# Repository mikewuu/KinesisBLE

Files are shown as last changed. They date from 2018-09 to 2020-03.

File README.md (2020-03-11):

# Wireless Kinesis Advantage BLE (Bluetooth Low Energy)

Turns the [Kinesis Advantage Keyboard](https://www.kinesis-ergo.com/shop/advantage2/) keyboard into a wireless BLE keyboard with a few extra features. Built with Adafruit's nRF52 Feather Arduino boards.

For instructions, see the **[wiki](https://github.com/sysdevmike/KinesisBLE/wiki)**. For more details on the build check out the **[project](https://hackaday.io/project/161578-wireless-ble-kinesis-advantage-custom-controller)**.

## Many thanks to

- [Yin Zhong](https://summivox.wordpress.com/2016/06/03/keyboard-matrix-scanning-and-debouncing/) - Explains a better way to handle debouncing.
- [Stapelberg](https://michael.stapelberg.ch/posts/2018-04-17-kinx-keyboard-controller/) - Double mention as I ported his debouncing used in his KinX controller to Matt's firmware.
- [Matt Vilim](https://github.com/mattvilim/FeatherCtrl) - New firmware is a fork of his FeatherCtrl project.
- [Adafruit](https://www.adafruit.com/product/3406) - Great documentation, libs and support.
- [afriggeri](https://github.com/afriggeri/kb) - The original firmware borrowed heavily from his [Blanck Keyboard](https://medium.com/@friggeri/the-blanck-keyboard-24afe12e81a) project.
- [Stapelberg](https://michael.stapelberg.de/posts/2013-03-21-kinesis_custom_controller/) - Michael Stapelberg's custom controller inspired this project. His PCB routing was inspirational.
- [Humble Hacker](http://humblehacker.com/blog/20100720/hacking-the-kinesis-contoured-keyboard/) - Detailed write-up helped me understand the keyboard matrix.
- [PCBgogo](http://www.pcbgogo.com) - All the boards were made by these guys. Fast turn-around.

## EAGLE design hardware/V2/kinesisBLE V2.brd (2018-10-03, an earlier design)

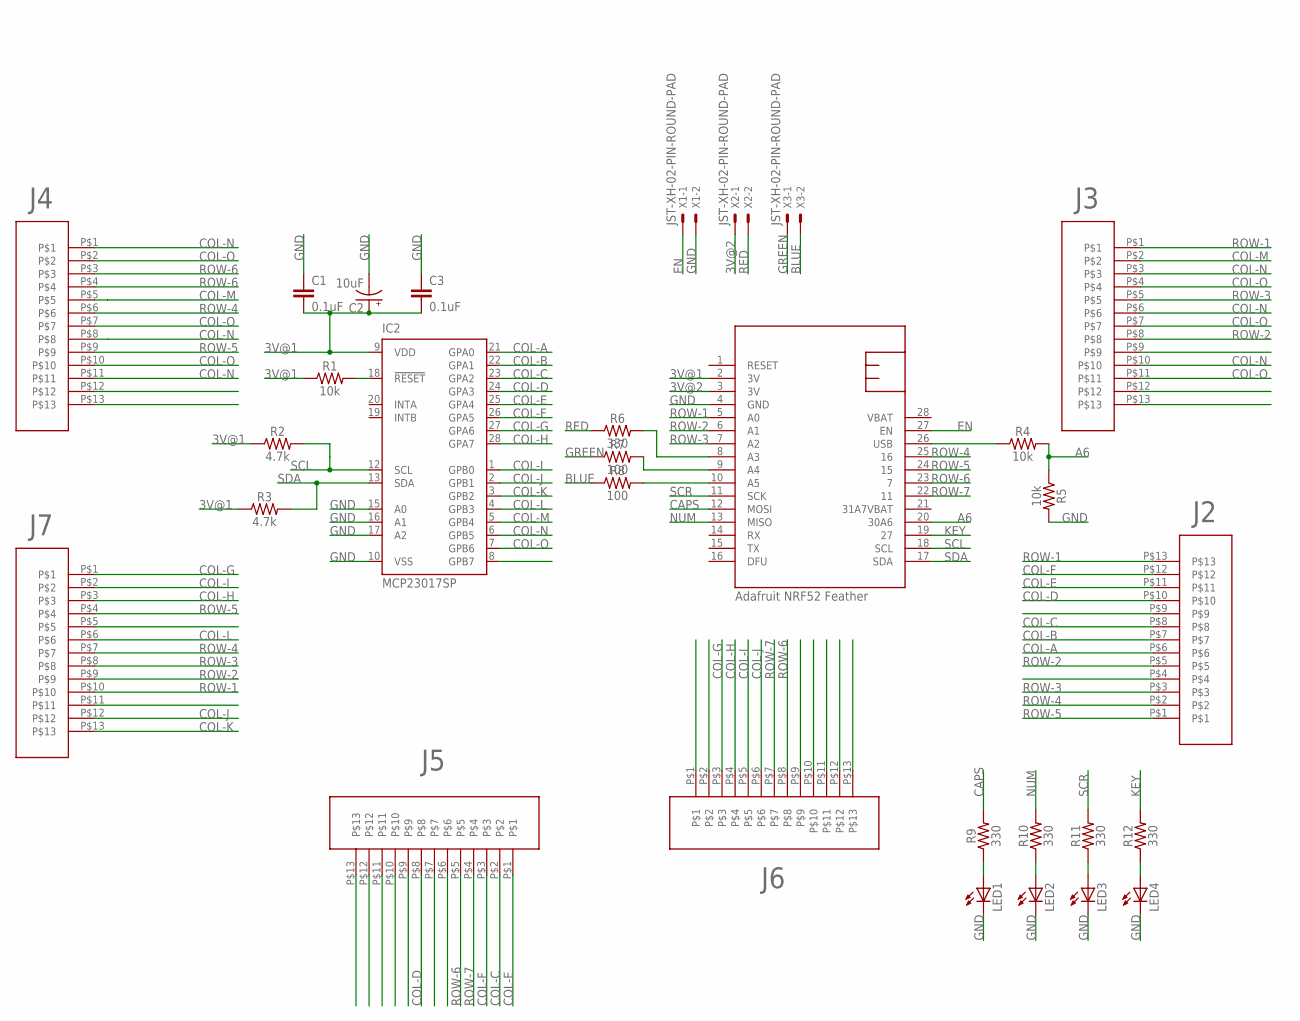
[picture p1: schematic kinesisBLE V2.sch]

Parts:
C1, C3: 0.1uF; CAP-PTH-SMALL-KIT
C2: 10uF; CPOL-RADIAL-2.5MM-5MM
IC2: MCP23017SP; DIL28-3
LED1, LED2, LED3, LED4: LED3MM
R1, R4, R5: 10k; AXIAL-0.3
R2, R3: 4.7k; AXIAL-0.3
R6, R9, R10, R11, R12: 330; AXIAL-0.3
R7, R8: 100; AXIAL-0.3
U$1: NRF52FEATHER
U$2, U$3, U$4, U$5, U$6, U$7: TOPLINKS_STAPELBERG
X1, X2, X3: JST-XH-02-PIN-ROUND-PAD; JST-XH-02-PACKAGE-ROUND-PAD

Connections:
3V@1: C1.2, C2.1 (+), C3.2, IC2.9 (VDD), R1.P$1 (1), R2.P$1 (1), R3.P$1 (1), U$1.2 (3V)
3V@2: U$1.3 (3V), X2.1
A6: R4.P$2 (2), R5.P$1 (1), U$1.20 (30A6)
BLUE: R8.P$1 (1), X3.2
CAPS: R9.P$2 (2), U$1.12 (MOSI)
COL-A: IC2.21 (GPA0), U$5.P$6
COL-B: IC2.22 (GPA1), U$5.P$7
COL-C: IC2.23 (GPA2), U$5.P$8, U$6.P$2
COL-D: IC2.24 (GPA3), U$5.P$10, U$6.P$8
COL-E: IC2.25 (GPA4), U$5.P$11, U$6.P$1
COL-F: IC2.26 (GPA5), U$5.P$12, U$6.P$3
COL-G: IC2.27 (GPA6), U$4.P$1, U$7.P$3
COL-H: IC2.28 (GPA7), U$4.P$3, U$7.P$4
COL-I: IC2.1 (GPB0), U$4.P$2, U$7.P$5
COL-J: IC2.2 (GPB1), U$4.P$12, U$7.P$6
COL-K: IC2.3 (GPB2), U$4.P$13
COL-L: IC2.4 (GPB3), U$4.P$6
COL-M: IC2.5 (GPB4), U$2.P$5, U$3.P$2
COL-N: IC2.6 (GPB5), U$2.P$1, U$2.P$8, U$2.P$11, U$3.P$3, U$3.P$6, U$3.P$10
COL-O: IC2.7 (GPB6), U$2.P$2, U$2.P$7, U$2.P$10, U$3.P$4, U$3.P$7, U$3.P$11
EN: U$1.27 (EN), X1.1
GND: C1.1, C2.2 (-), C3.1, IC2.10 (VSS), IC2.15 (A0), IC2.16 (A1), IC2.17 (A2), LED1.K (C), LED2.K (C), LED3.K (C), LED4.K (C), R5.P$2 (2), U$1.4 (GND), X1.2
GREEN: R7.P$1 (1), X3.1
KEY: R12.P$2 (2), U$1.19 (27)
unnamed: LED1.A, R9.P$1 (1)
unnamed: IC2.18 (!RESET), R1.P$2 (2)
unnamed: R4.P$1 (1), U$1.26 (USB)
unnamed: R6.P$2 (2), U$1.8 (A3)
unnamed: R7.P$2 (2), U$1.9 (A4)
unnamed: R8.P$2 (2), U$1.10 (A5)
unnamed: LED2.A, R10.P$1 (1)
unnamed: LED3.A, R11.P$1 (1)
unnamed: LED4.A, R12.P$1 (1)
NUM: R10.P$2 (2), U$1.13 (MISO)
RED: R6.P$1 (1), X2.2
ROW-1: U$1.5 (A0), U$3.P$1, U$4.P$10, U$5.P$13
ROW-2: U$1.6 (A1), U$3.P$8, U$4.P$9, U$5.P$5
ROW-3: U$1.7 (A2), U$3.P$5, U$4.P$8, U$5.P$3
ROW-4: U$1.25 (16), U$2.P$6, U$4.P$7, U$5.P$2
ROW-5: U$1.24 (15), U$2.P$9, U$4.P$4, U$5.P$1
ROW-6: U$1.23 (7), U$2.P$3, U$2.P$4, U$6.P$5, U$7.P$8
ROW-7: U$1.22 (11), U$6.P$4, U$7.P$7
SCL: IC2.12 (SCL), R2.P$2 (2), U$1.18 (SCL)
SCR: R11.P$2 (2), U$1.11 (SCK)
SDA: IC2.13 (SDA), R3.P$2 (2), U$1.17 (SDA)
VBAT: U$1.28 (VBAT)

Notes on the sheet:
Adafruit NRF52 Feather

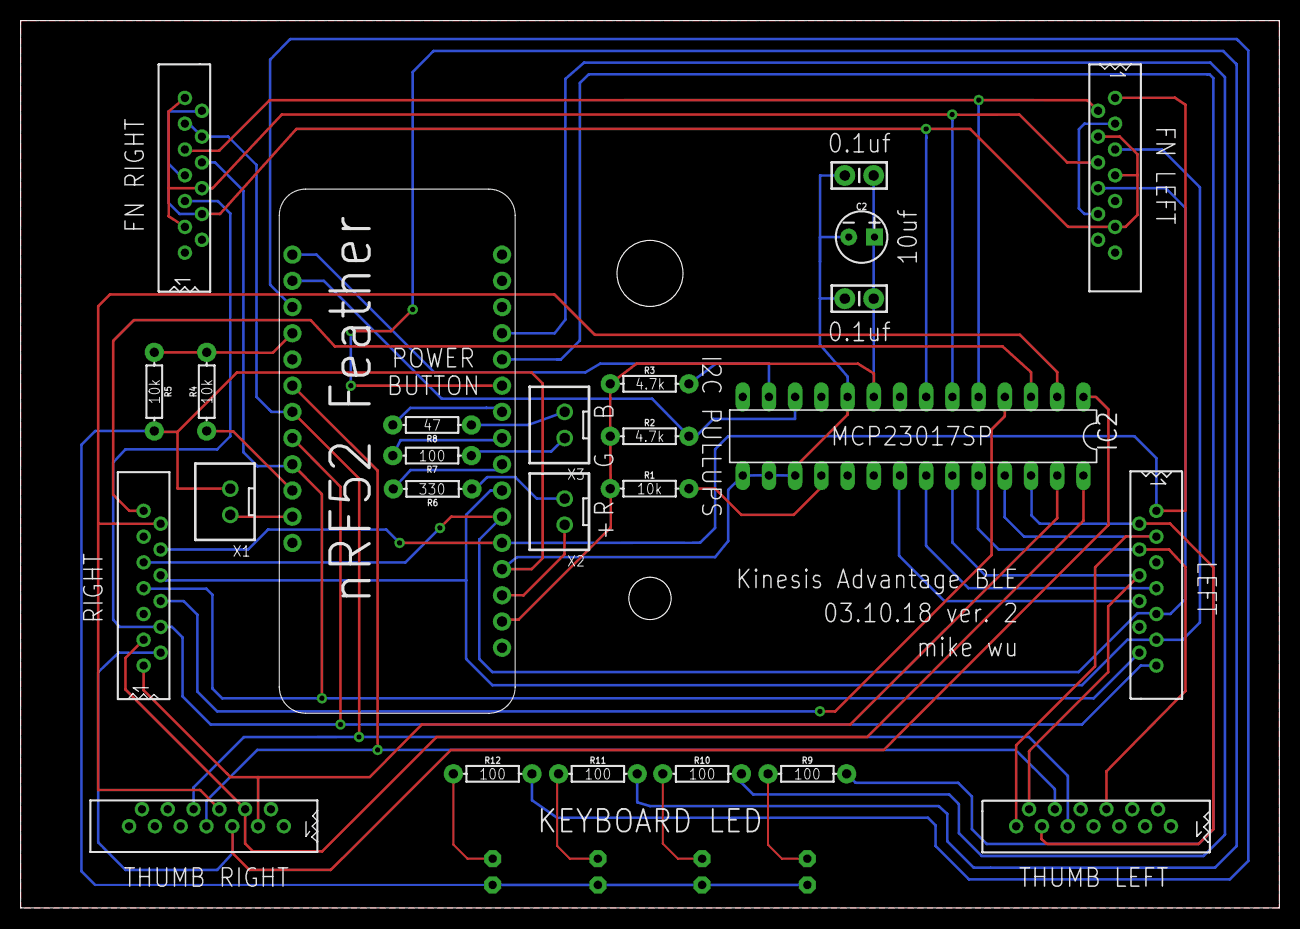
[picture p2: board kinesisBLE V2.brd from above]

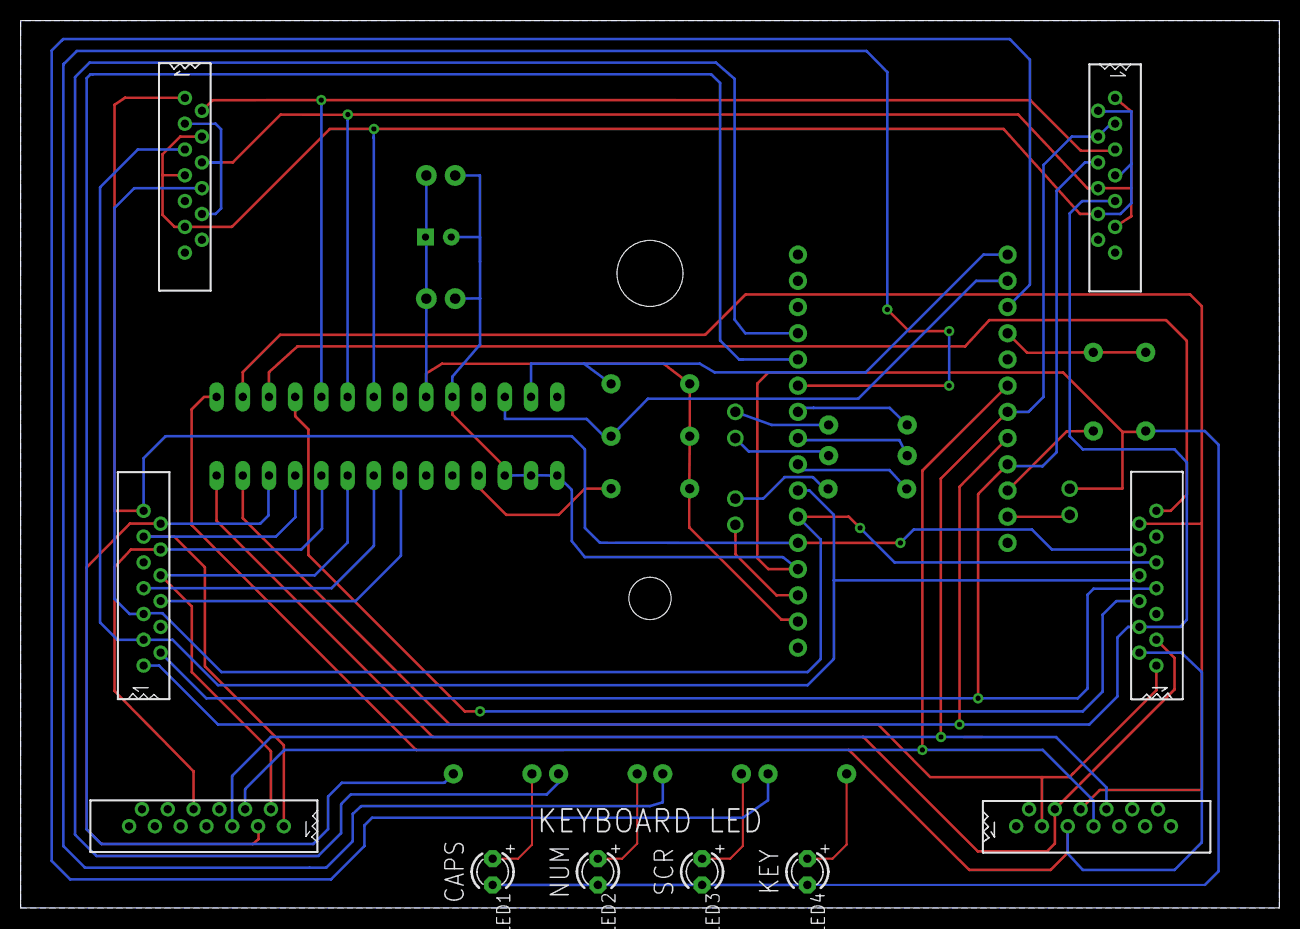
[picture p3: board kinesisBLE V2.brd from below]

Board: 2 copper layers, 122.0 x 86.0 mm, 30 parts (7 on the bottom side), 45 nets.

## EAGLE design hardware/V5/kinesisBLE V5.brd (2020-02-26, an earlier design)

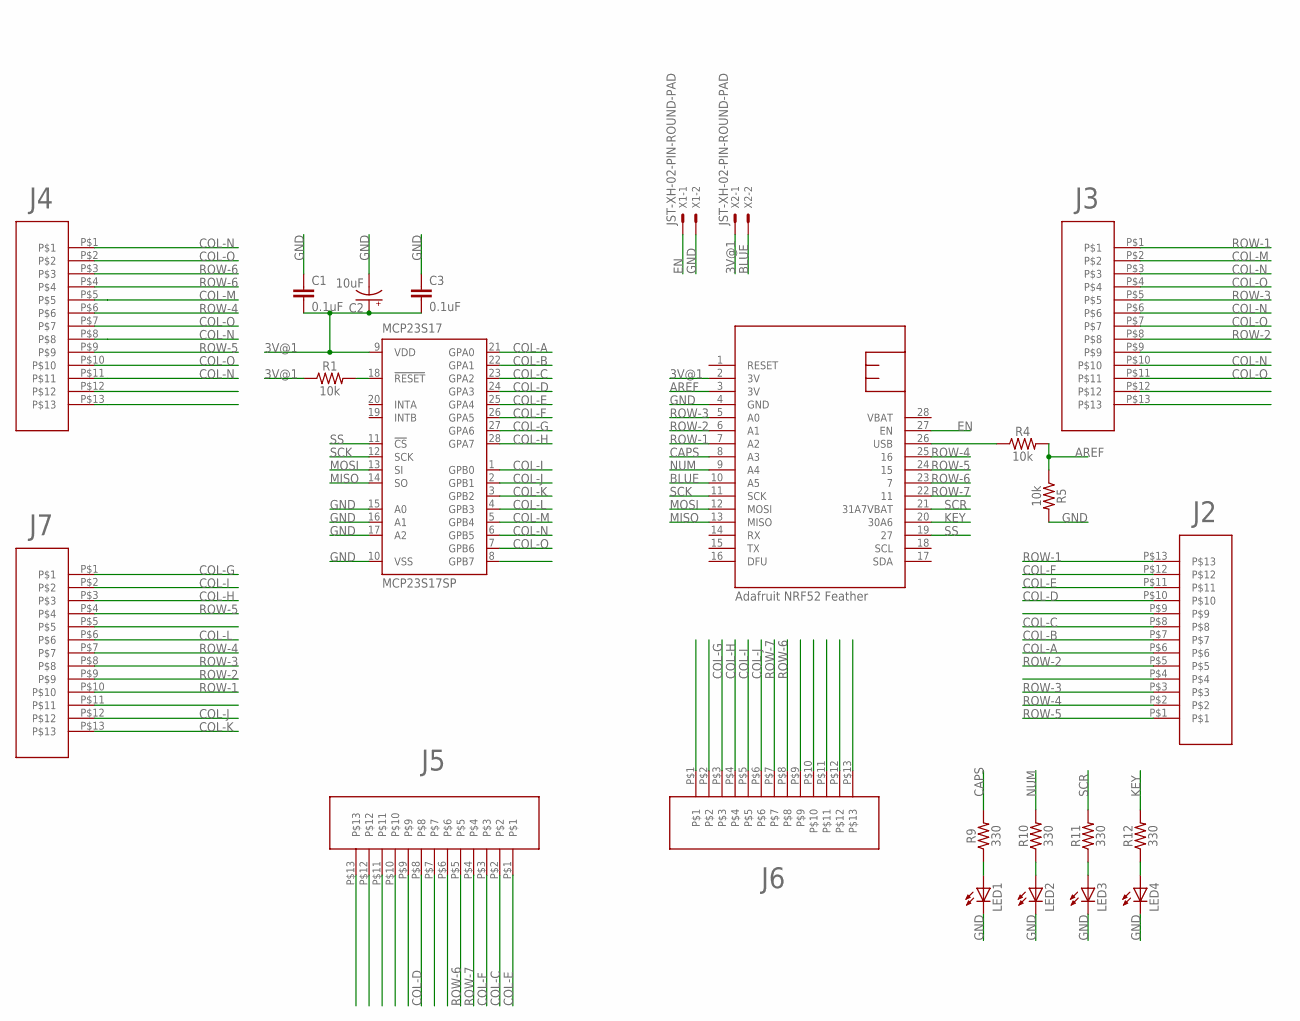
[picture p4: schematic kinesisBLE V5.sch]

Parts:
C1, C3: 0.1uF; CAP-PTH-SMALL-KIT
C2: 10uF; CPOL-RADIAL-2.5MM-5MM
LED1, LED2, LED3, LED4: LED3MM
MCP23S17: MCP23S17SP; DIL28-3
R1, R4, R5: 10k; AXIAL-0.3
R9, R10, R11, R12: 330; AXIAL-0.3
U$1: NRF52FEATHER
U$2, U$3, U$4, U$5, U$6, U$7: TOPLINKS_STAPELBERG
X1, X2: JST-XH-02-PIN-ROUND-PAD; JST-XH-02-PACKAGE-ROUND-PAD

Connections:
3V@1: C1.2, C2.1 (+), C3.2, MCP23S17.9 (VDD), R1.P$1 (1), U$1.2 (3V), X2.1
AREF: R4.P$2 (2), R5.P$1 (1), U$1.3 (3V)
BLUE: U$1.10 (A5), X2.2
CAPS: R9.P$2 (2), U$1.8 (A3)
COL-A: MCP23S17.21 (GPA0), U$5.P$6
COL-B: MCP23S17.22 (GPA1), U$5.P$7
COL-C: MCP23S17.23 (GPA2), U$5.P$8, U$6.P$2
COL-D: MCP23S17.24 (GPA3), U$5.P$10, U$6.P$8
COL-E: MCP23S17.25 (GPA4), U$5.P$11, U$6.P$1
COL-F: MCP23S17.26 (GPA5), U$5.P$12, U$6.P$3
COL-G: MCP23S17.27 (GPA6), U$4.P$1, U$7.P$3
COL-H: MCP23S17.28 (GPA7), U$4.P$3, U$7.P$4
COL-I: MCP23S17.1 (GPB0), U$4.P$2, U$7.P$5
COL-J: MCP23S17.2 (GPB1), U$4.P$12, U$7.P$6
COL-K: MCP23S17.3 (GPB2), U$4.P$13
COL-L: MCP23S17.4 (GPB3), U$4.P$6
COL-M: MCP23S17.5 (GPB4), U$2.P$5, U$3.P$2
COL-N: MCP23S17.6 (GPB5), U$2.P$1, U$2.P$8, U$2.P$11, U$3.P$3, U$3.P$6, U$3.P$10
COL-O: MCP23S17.7 (GPB6), U$2.P$2, U$2.P$7, U$2.P$10, U$3.P$4, U$3.P$7, U$3.P$11
EN: U$1.27 (EN), X1.1
GND: C1.1, C2.2 (-), C3.1, LED1.K (C), LED2.K (C), LED3.K (C), LED4.K (C), MCP23S17.10 (VSS), MCP23S17.15 (A0), MCP23S17.16 (A1), MCP23S17.17 (A2), R5.P$2 (2), U$1.4 (GND), X1.2
KEY: R12.P$2 (2), U$1.20 (30A6)
MISO: MCP23S17.14 (SO), U$1.13 (MISO)
MOSI: MCP23S17.13 (SI), U$1.12 (MOSI)
unnamed: LED1.A, R9.P$1 (1)
unnamed: MCP23S17.18 (!RESET), R1.P$2 (2)
unnamed: R4.P$1 (1), U$1.26 (USB)
unnamed: LED2.A, R10.P$1 (1)
unnamed: LED3.A, R11.P$1 (1)
unnamed: LED4.A, R12.P$1 (1)
NUM: R10.P$2 (2), U$1.9 (A4)
ROW-1: U$1.7 (A2), U$3.P$1, U$4.P$10, U$5.P$13
ROW-2: U$1.6 (A1), U$3.P$8, U$4.P$9, U$5.P$5
ROW-3: U$1.5 (A0), U$3.P$5, U$4.P$8, U$5.P$3
ROW-4: U$1.25 (16), U$2.P$6, U$4.P$7, U$5.P$2
ROW-5: U$1.24 (15), U$2.P$9, U$4.P$4, U$5.P$1
ROW-6: U$1.23 (7), U$2.P$3, U$2.P$4, U$6.P$5, U$7.P$8
ROW-7: U$1.22 (11), U$6.P$4, U$7.P$7
SCK: MCP23S17.12 (SCK), U$1.11 (SCK)
SCR: R11.P$2 (2), U$1.21 (31A7VBAT)
SS: MCP23S17.11 (!CS), U$1.19 (27)
VBAT: U$1.28 (VBAT)

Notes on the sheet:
Adafruit NRF52 Feather

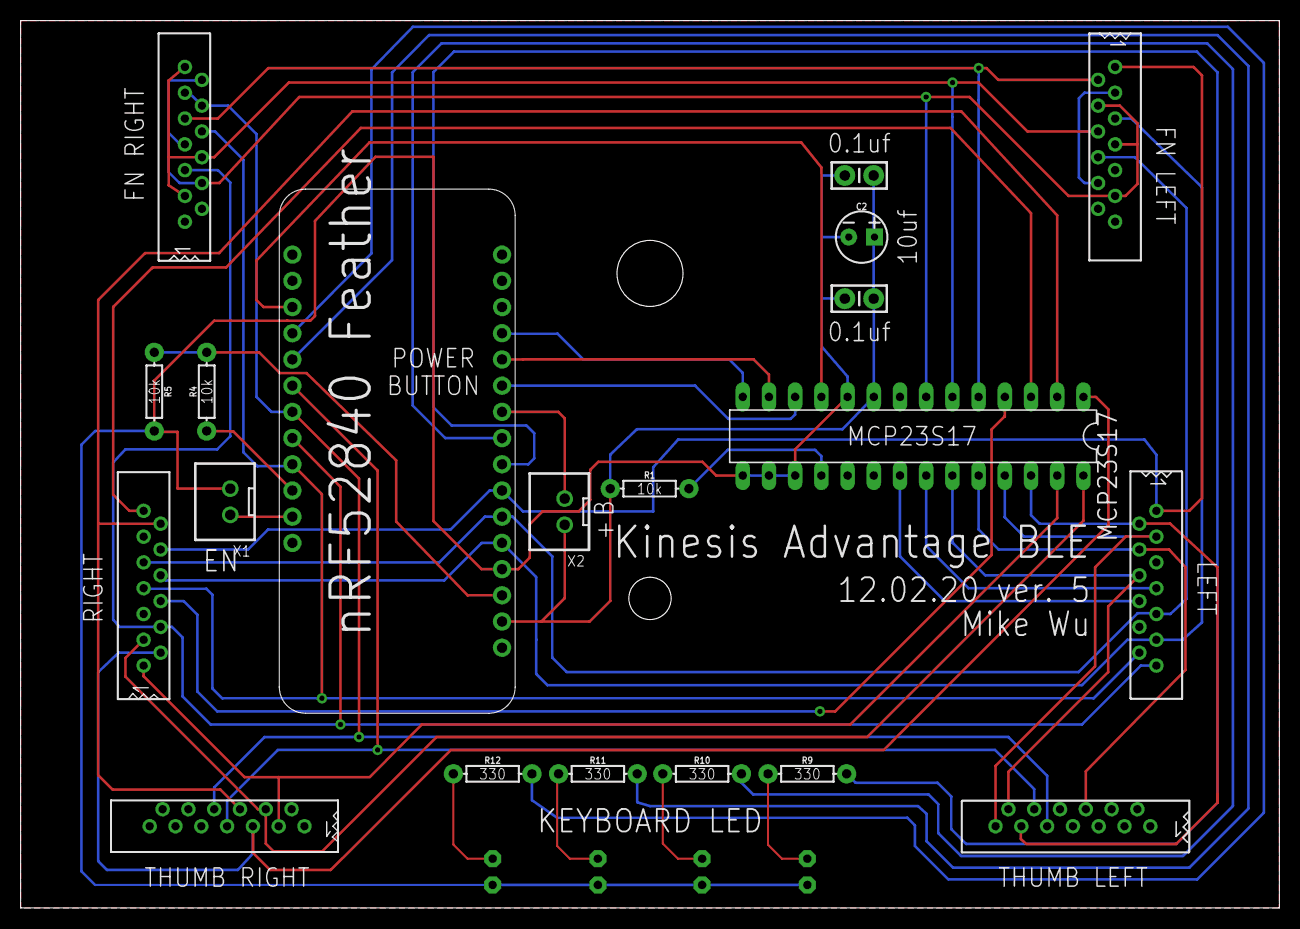
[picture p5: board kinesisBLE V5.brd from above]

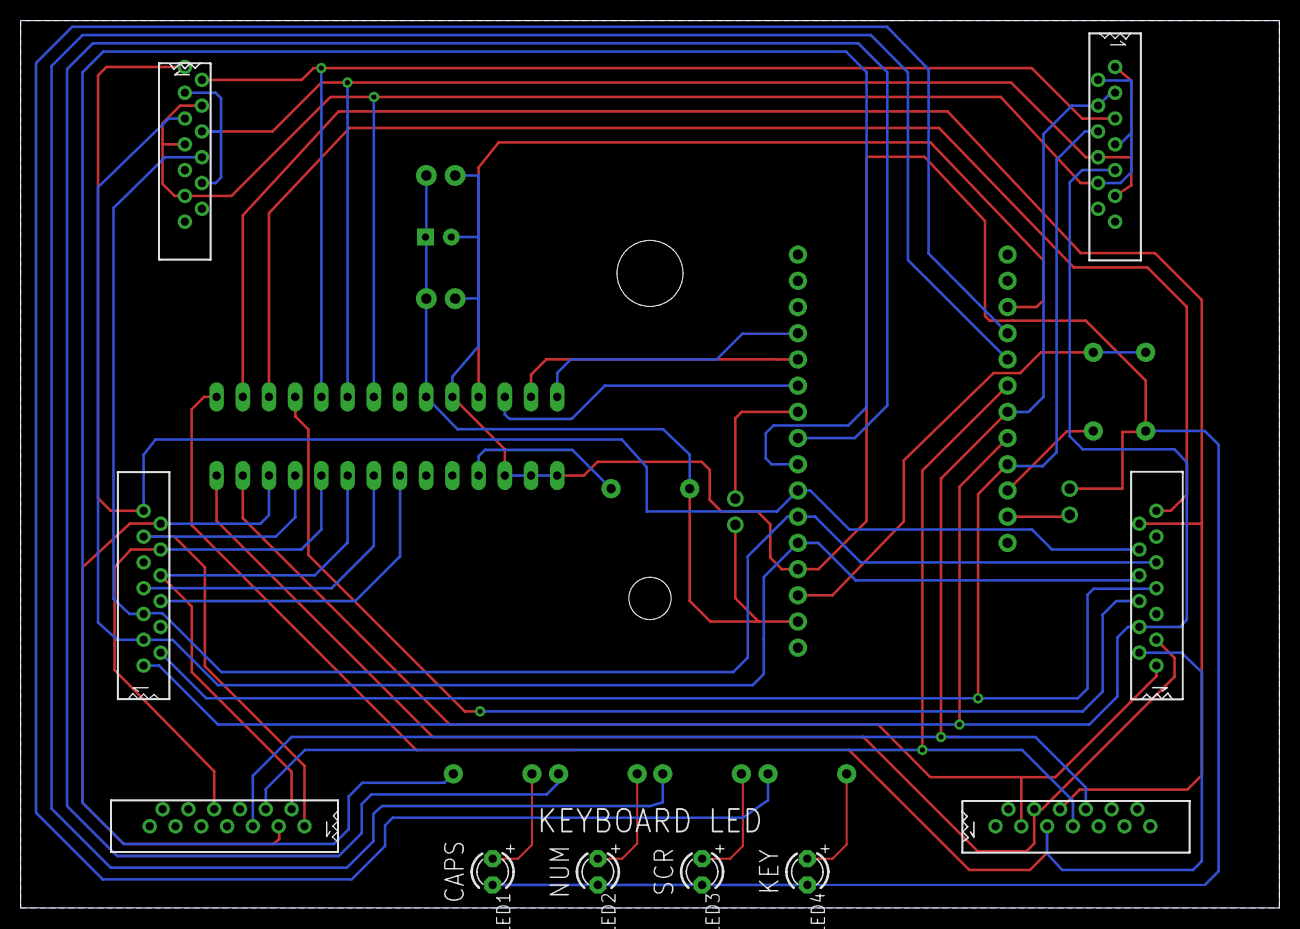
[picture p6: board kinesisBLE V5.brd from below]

Board: 2 copper layers, 122.0 x 86.0 mm, 24 parts (7 on the bottom side), 41 nets.

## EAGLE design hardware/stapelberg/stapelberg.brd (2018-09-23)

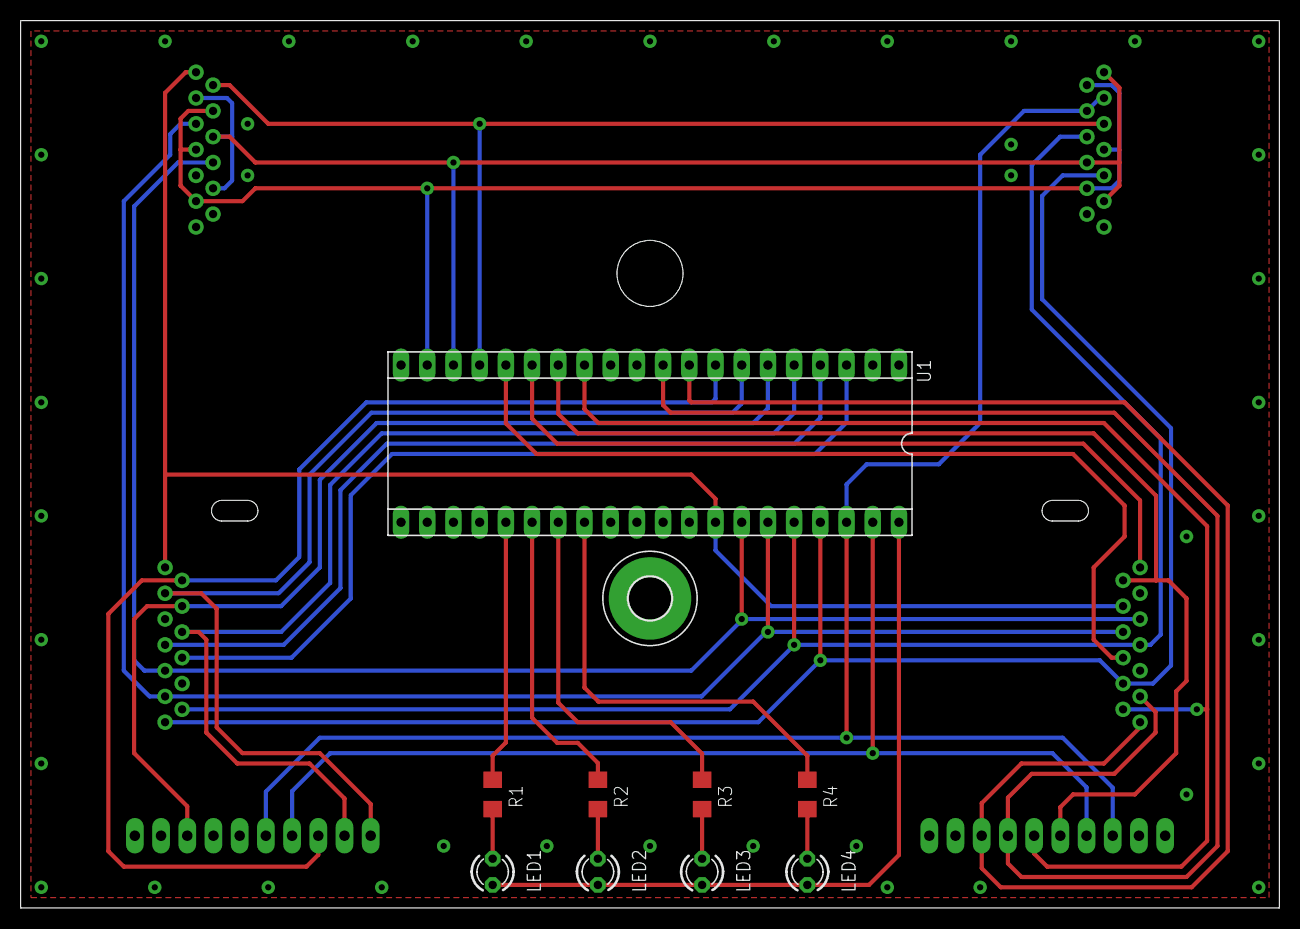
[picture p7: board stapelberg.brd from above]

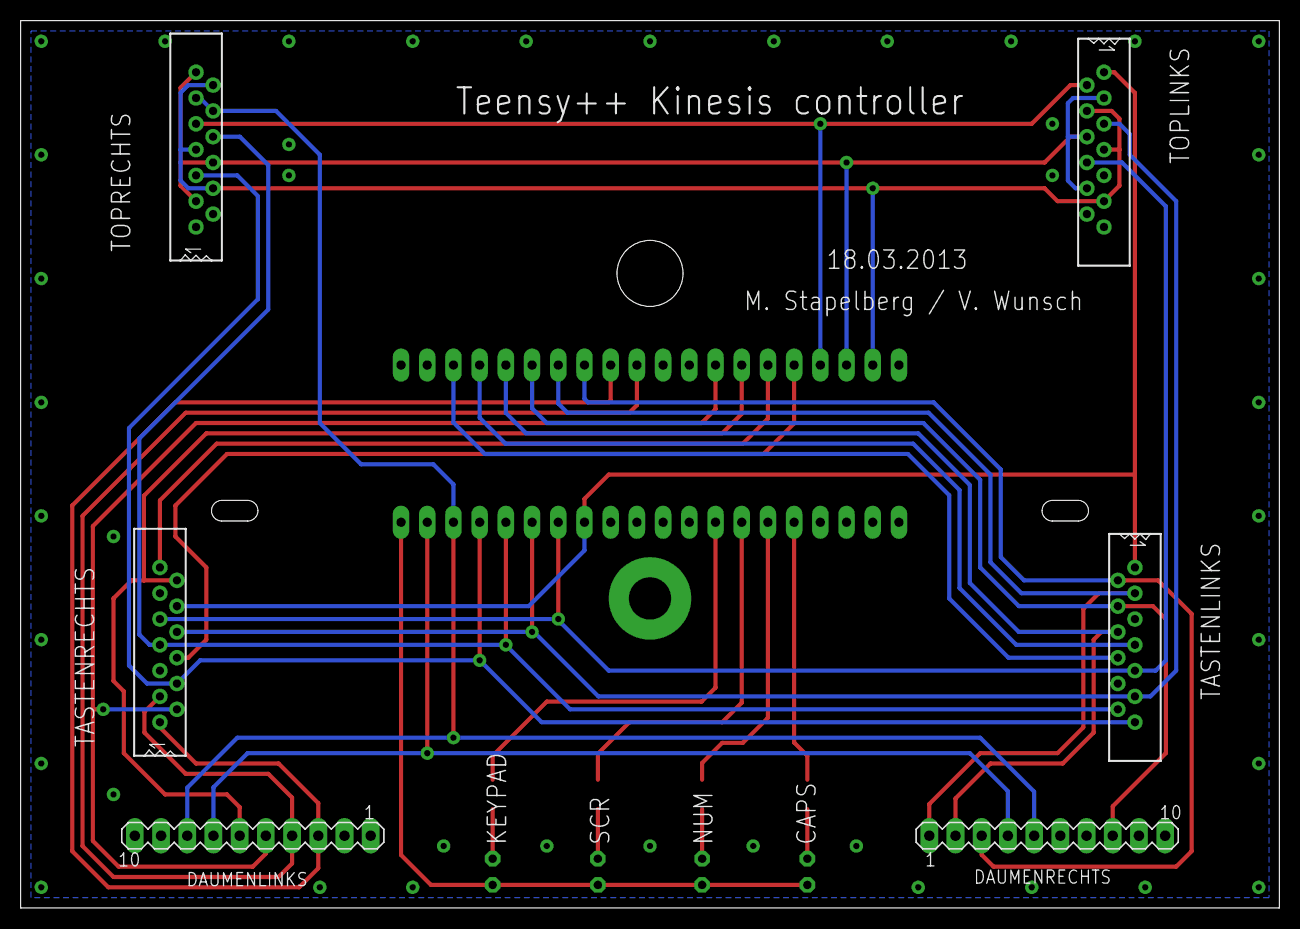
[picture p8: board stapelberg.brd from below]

Board: 2 copper layers, 122.0 x 86.0 mm, 16 parts (6 on the bottom side), 31 nets.

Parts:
DAUMENLINKS: MA10-1
DAUMENRECHTS: MA10-1
H1: MOUNT-PAD-ROUND4.1; 4,1-PAD
LED1, LED2, LED3, LED4: LED3MM
R1, R2, R3, R4: R1206
TASTENLINKS: 39-53-2355; 39-53-2135
TASTENRECHTS: 39-53-2355; 39-53-2135
TOPLINKS: 39-53-2355; 39-53-2135
TOPRECHTS: 39-53-2355; 39-53-2135
U1: C-TEENSY++; TEENSY++

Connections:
B0: TASTENLINKS.P$1, TASTENRECHTS.P$10, TOPLINKS.P$1, U1.B0
B1: TASTENLINKS.P$9, TASTENRECHTS.P$9, TOPLINKS.P$8, U1.B1
B2: TASTENLINKS.P$11, TASTENRECHTS.P$8, TOPLINKS.P$5, U1.B2
B3: TASTENLINKS.P$12, TASTENRECHTS.P$7, TOPRECHTS.P$8, U1.B3
B4: TASTENLINKS.P$13, TASTENRECHTS.P$4, TOPRECHTS.P$5, U1.B4
B5: DAUMENLINKS.8, DAUMENRECHTS.5, TOPRECHTS.P$10, TOPRECHTS.P$11, U1.B5
B6: DAUMENLINKS.7, DAUMENRECHTS.4, U1.B6
C0: DAUMENLINKS.5, TASTENRECHTS.P$2, U1.C0
C1: DAUMENLINKS.6, TASTENRECHTS.P$12, U1.C1
C2: TASTENRECHTS.P$13, U1.C2
C3: TASTENRECHTS.P$6, U1.C3
C4: TOPLINKS.P$2, TOPRECHTS.P$9, U1.C4
C5: TOPLINKS.P$3, TOPLINKS.P$6, TOPLINKS.P$10, TOPRECHTS.P$3, TOPRECHTS.P$6, TOPRECHTS.P$13, U1.C5
C6: TOPLINKS.P$4, TOPLINKS.P$7, TOPLINKS.P$11, TOPRECHTS.P$4, TOPRECHTS.P$7, TOPRECHTS.P$12, U1.C6
D0: TASTENLINKS.P$8, U1.D0
D1: TASTENLINKS.P$7, U1.D1
D2: DAUMENRECHTS.2, TASTENLINKS.P$6, U1.D2
D3: DAUMENRECHTS.8, TASTENLINKS.P$4, U1.D3
D4: DAUMENRECHTS.1, TASTENLINKS.P$3, U1.D4
D5: DAUMENRECHTS.3, TASTENLINKS.P$2, U1.D5
D6: DAUMENLINKS.3, TASTENRECHTS.P$1, U1.D6
D7: DAUMENLINKS.4, TASTENRECHTS.P$3, U1.D7
unnamed: R1.2, U1.F3
unnamed: R2.2, U1.F2
unnamed: R3.2, U1.F1
unnamed: R4.2, U1.F0
unnamed: LED1.A, LED2.A, LED3.A, LED4.A, U1.+5V
unnamed: LED4.K, R4.1
unnamed: LED3.K, R3.1
unnamed: LED2.K, R2.1
unnamed: LED1.K, R1.1

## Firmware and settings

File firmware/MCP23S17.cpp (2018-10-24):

/*
  MCP23S17.cpp  Version 0.2
  Microchip MCP23S17 SPI I/O Expander Class for Arduino
  Created by Cort Buffington & Keith Neufeld
  March, 2011
  January, 2013
  January, 2015
  February, 2016

  Features Implemented (by word and bit):
    I/O Direction
    Pull-up on/off
    Input inversion
    Output write
    Input read

  Interrupt features are not implemented in this version
  byte based (portA, portB) functions are not implemented in this version

  NOTE:  Addresses below are only valid when IOCON.BANK=0 (register addressing mode)
         This means one of the control register values can change register addresses!
         The default values is 0, so that's how we're using it.

         All registers except ICON (0xA and 0xB) are paired as A/B for each 8-bit GPIO port.
         Comments identify the port's name, and notes on how it is used.

         *THIS CLASS ENABLES THE ADDRESS PINS ON ALL CHIPS ON THE BUS WHEN THE FIRST CHIP OBJECT IS INSTANTIATED!

  USAGE: All Read/Write functions except wordWrite are implemented in two different ways.
         Individual pin values are set by referencing "pin #" and On/Off, Input/Output or High/Low where
         portA represents pins 0-7 and portB 8-15. So to set the most significant bit of portB, set pin # 15.
         To Read/Write the values for the entire chip at once, a word mode is supported buy passing a
         single argument to the function as 0x(portB)(portA). I/O mode Output is represented by 0.
         The wordWrite function was to be used internally, but was made public for advanced users to have
         direct and more efficient control by writing a value to a specific register pair.

  VERSION RELESE NOTES:
        V0.2
        Changed direct manipulation of pin 10 on ATMega168/328 via "PORTB" to use digitalWrite on an arbitrary
        SlaveSelect pin passed to the object through the constructor
*/

#include <SPI.h>                 // Arduino IDE SPI library - uses AVR hardware SPI features
#include "MCP23S17.h"            // Header files for this class

// Defines to keep logical information symbolic go here

#ifndef HIGH
#define    HIGH          (1)
#endif

#ifndef LOW
#define    LOW           (0)
#endif

#ifndef ON
#define    ON            (1)
#endif

#ifndef OFF
#define    OFF           (0)
#endif

// Here we have things for the SPI bus configuration

#define    CLOCK_DIVIDER (2)           // SPI bus speed to be 1/2 of the processor clock speed - 8MHz on most Arduinos

// Control byte and configuration register information - Control Byte: "0100 A2 A1 A0 R/W" -- W=0

#define    OPCODEW       (0b01000000)  // Opcode for MCP23S17 with LSB (bit0) set to write (0), address OR'd in later, bits 1-3
#define    OPCODER       (0b01000001)  // Opcode for MCP23S17 with LSB (bit0) set to read (1), address OR'd in later, bits 1-3
#define    ADDR_ENABLE   (0b00001000)  // Configuration register for MCP23S17, the only thing we change is enabling hardware addressing

// Constructor to instantiate an instance of MCP to a specific chip (address)

MCP::MCP(uint8_t address, uint8_t ss) {
  _address     = constrain(address, 0, 7);
  _ss          = ss;
  _modeCache   = 0xFFFF;                // Default I/O mode is all input, 0xFFFF
  _outputCache = 0x0000;                // Default output state is all off, 0x0000
  _pullupCache = 0x0000;                // Default pull-up state is all off, 0x0000
  _invertCache = 0x0000;                // Default input inversion state is not inverted, 0x0000
};

void MCP::begin() {
  ::pinMode(_ss, OUTPUT);               // Set SlaveSelect pin as an output
  ::digitalWrite(_ss, HIGH);            // Set SlaveSelect HIGH (chip de-selected)
  SPI.begin();                          // Start up the SPI bus
  //SPI.setClockDivider(CLOCK_DIVIDER); // Sets the SPI bus speed
  //SPI.setBitOrder(MSBFIRST);          // Sets SPI bus bit order (this is the default, setting it for good form!)
  //SPI.setDataMode(SPI_MODE0);         // Sets the SPI bus timing mode (this is the default, setting it for good form!)
  byteWrite(IOCON, ADDR_ENABLE);
}

// GENERIC BYTE WRITE - will write a byte to a register, arguments are register address and the value to write

void MCP::byteWrite(uint8_t reg, uint8_t value) {      // Accept the register and byte
  ::digitalWrite(_ss, LOW);                            // Take slave-select low
  SPI.transfer(OPCODEW | (_address << 1));             // Send the MCP23S17 opcode, chip address, and write bit
  SPI.transfer(reg);                                   // Send the register we want to write
  SPI.transfer(value);                                 // Send the byte
  ::digitalWrite(_ss, HIGH);                           // Take slave-select high
}

// GENERIC WORD WRITE - will write a word to a register pair, LSB to first register, MSB to next higher value register 

void MCP::wordWrite(uint8_t reg, unsigned int word) {  // Accept the start register and word 
  ::digitalWrite(_ss, LOW);                            // Take slave-select low
  SPI.transfer(OPCODEW | (_address << 1));             // Send the MCP23S17 opcode, chip address, and write bit
  SPI.transfer(reg);                                   // Send the register we want to write 
  SPI.transfer((uint8_t) (word));                      // Send the low byte (register address pointer will auto-increment after write)
  SPI.transfer((uint8_t) (word >> 8));                 // Shift the high byte down to the low byte location and send
  ::digitalWrite(_ss, HIGH);                           // Take slave-select high
}

// MODE SETTING FUNCTIONS - BY PIN AND BY WORD

void MCP::pinMode(uint8_t pin, uint8_t mode) {  // Accept the pin # and I/O mode
  if (pin < 1 | pin > 16) return;               // If the pin value is not valid (1-16) return, do nothing and return
  if (mode == INPUT) {                          // Determine the mode before changing the bit state in the mode cache
    _modeCache |= 1 << (pin - 1);               // Since input = "HIGH", OR in a 1 in the appropriate place
  } else {
    _modeCache &= ~(1 << (pin - 1));            // If not, the mode must be output, so and in a 0 in the appropriate place
  }
  wordWrite(IODIRA, _modeCache);                // Call the generic word writer with start register and the mode cache
}

void MCP::pinMode(unsigned int mode) {     // Accept the word…
  wordWrite(IODIRA, mode);                 // Call the the generic word writer with start register and the mode cache
  _modeCache = mode;
}

// THE FOLLOWING WRITE FUNCTIONS ARE NEARLY IDENTICAL TO THE FIRST AND ARE NOT INDIVIDUALLY COMMENTED

// WEAK PULL-UP SETTING FUNCTIONS - BY WORD AND BY PIN

void MCP::pullupMode(uint8_t pin, uint8_t mode) {
  if (pin < 1 | pin > 16) return;
  if (mode == ON) {
    _pullupCache |= 1 << (pin - 1);
  } else {
    _pullupCache &= ~(1 << (pin -1));
  }
  wordWrite(GPPUA, _pullupCache);
}


void MCP::pullupMode(unsigned int mode) { 
  wordWrite(GPPUA, mode);
  _pullupCache = mode;
}
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

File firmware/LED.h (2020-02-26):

#ifndef LED_H
#define LED_H

#include <bluefruit.h>

class LED {
  public:
  
    const static uint8_t CAPS_PIN = A3;
    const static uint8_t NUM_PIN = A4;
    const static uint8_t SCR_PIN = 9;
    const static uint8_t KEY_PIN = 6; 
    
    LED(void);
    void begin(void);
    void numLEDsOnForDuration(int num, unsigned long duration);
    void process(void);
    void offAll(void);
    void flashWithSpeed(bool speed);
    void stopFlashing(void);
    
  private:

    const uint8_t POWER_BUTTON_PIN = A5;    
    const uint8_t powerButtonBrightness = 175;
    bool shouldTurnOffAfterDuration;
    unsigned long onTime;
    unsigned long onDuration;
    bool isFlashing;
    bool flashingLedOn;
    bool flashSpeed;
    unsigned long lastFlashTime;
    unsigned long slowFlashGap;
    unsigned long fastFlashGap;
    
    void setLED(int pin, bool state);
    void setAllLEDs(bool state);
    void powerButtonOn(void);
    void powerButtonOff(void);
    void LEDsOff(void);
};


#endif

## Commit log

2016-11-28 Rebuild because Bluefruit died, switched a few pins around
2017-03-04 Lower BLE power level
2018-09-23 Include stapelberg board files
    [stapelberg.brd]
2018-09-24 Remove reading battery ADC and added comments
2018-09-24 switched Q and A keycodes
2018-09-24 Set bluetooth settings from current nRF52 setup
2018-09-27 Switch columns and rows. Detects key presses according to Humble Hacker matrix.
2018-09-28 First complete working version. No LEDs.
2018-09-28 Battery indicator LEDs
2018-09-28 Power Button LED
2018-09-29 Fix measure battery every 10 seconds
2018-10-01 Test power-saving code
2018-10-01 Battery LED off timer. Shutdown (deep-sleep) after inactivity.
2018-10-01 Decrease Blue power button led to 80/255 = 1.9mA. Remove built-in LED sleep indicator that was used for testing.
2018-10-01 Add Eagle files
    [kinesisBLE.brd, kinesisBLE.sch, stapelberg.brd]
2018-10-02 Debounce once as MCP takes 20-30ms to go through one loop anyway. Fix use correct pins for LEDS and power button.
2018-10-03 Change LED pins from Serial. Fix not waking up from shutdown.
2018-10-03 Add charging animation. Make power button more orange when charging.
2018-10-03 Fix charging animation to stop at actual level when unplugged.
2018-10-03 V2 Board. Re-route LEDs to not use Serial pins.
    [kinesisBLE V1.brd, kinesisBLE V1.sch, kinesisBLE V2.brd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]
2018-10-04 Check if full from battery mv instead of reading USB.
2018-10-04 Go back to measuring USB voltage with smoothing
2018-10-10 Increase Power LED blue power to 125 (2mA). More keymap mappings for second layer.
2018-10-10 Raised layer keymaps: brackets and quotes.
2018-10-16 Remove Serial.begin for power saving
    [kinesisBLE V1.brd, kinesisBLE V1.sch]
2018-10-18 Set up with SPI and power saving
2018-10-19 Use v3 board pins
    [kinesisBLE V1.brd, kinesisBLE V1.sch, kinesisBLE V2.brd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]
2018-10-22 v3 board files
    [kinesisBLE V3.brd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]
2018-10-24 Turned power led back on
2018-10-28 V4 - Took LED(s) off TX/RX. Blue button only (lost RGB) to fix CP2104 battery drain.
    [kinesisBLE V3.brd, kinesisBLE V3.sch, kinesisBLE V4.brd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]
2018-10-30 Removed all power / battery features due to ADC current leak
2018-10-30 Fixed current drain issue due to FPU
2018-10-31 Reduce battery indicator LED on time from 5mins to 30 seconds
2018-11-16 lowered battery led brightness and increased duration to 3 mins.
2018-11-16 bug fix: led didn't blink when charging after switching to analogWrite.
2018-11-17 indicate battery level on progm key
2018-11-17 keyp to show battery level and progm to shutdown
2018-11-18 Featuer: Rest Timer
2018-11-19 changed rest timer settings
2019-01-28 flash led to indicate cleared
2019-02-11 cleanup setup. remove redundant comments. set work afk timer to 20mins
2019-04-22 BREAKING CHANGE - Revert to v3 pin numbers for use with nRF8240. Make sure you are building v3 (not v4!) board from this point forward.
2019-05-01 Add V4 gerbers.
    [kinesisBLE V4.GBL, kinesisBLE V4.GBO, kinesisBLE V4.GBS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]
2019-06-09 Use new firmare.
    [kinesisBLE V1.brd, kinesisBLE V1.sch, kinesisBLE V2.brd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]
2019-06-19 Increase bluetooth power.
2019-06-19 Go back to nrf52 0.8.6 because analogWrite would turn on bluetooth LED on 0.9.2.
2019-07-29 Set capslock back to capslock instead of esc.
2019-07-30 Implement Power and LED.
2019-07-30 Show battery level on power on.
2019-08-01 Move led logic into LED class.
2019-08-01 Add LED flash.
2019-08-01 Implement Pomodoro timer.
2019-09-06 Bind caps to esc. And program to hyper (f18, implemented in hammerspoon)
2020-02-14 V5 Board for nRF52840
    [kinesisBLE V5.brd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]
2020-02-14 Switch to nRF52840 v5 board pins
2020-02-26 Works! -- Set blue/power button pin to A5
2020-02-26 Allow opt-in rest timer from config
2020-02-27 Clean up hardware folder
    [kinesisBLE V1.brd, kinesisBLE V1.sch, kinesisBLE V2.brd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]
2021-03-21 Add v6 gerbers
    [kinesisBLE V6.GBL, kinesisBLE V6.GBO, kinesisBLE V6.GBS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]

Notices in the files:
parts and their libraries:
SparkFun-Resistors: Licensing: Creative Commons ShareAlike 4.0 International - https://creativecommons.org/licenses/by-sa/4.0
